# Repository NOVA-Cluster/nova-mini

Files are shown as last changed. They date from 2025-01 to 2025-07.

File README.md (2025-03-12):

# Nova Mini Project Suite

## Overview
The Nova Mini project suite consists of two main components that work together to create an interactive memory game experience:

1. Nova Mini (Receiver)
2. Nova Mini Remote (Sender)

These devices communicate wirelessly using ESP-NOW protocol to create an engaging, interactive game experience based on the classic Simon memory game.

## Components

### Nova Mini (Receiver)
The main game controller that:
- Handles core game logic and state management
- Controls LED patterns and audio feedback
- Processes player inputs
- Manages game progression through levels and rounds
- Provides hardware-level control and feedback

### Nova Mini Remote (Sender)
The user interface controller that:
- Initiates game commands and controls
- Sends instructions to the Nova Mini receiver
- Provides real-time game state updates
- Offers enhanced game mode features
- Enables remote gameplay control

## Technical Stack

### Hardware
Both devices are built on the ESP32 platform, featuring:
- ESP32 microcontroller
- LED indicators for visual feedback
- Push buttons for user input
- Buzzer for audio feedback
- Custom PCB design

### Software
Built using modern embedded development tools and frameworks:
- PlatformIO development environment
- Arduino framework for ESP32
- ESP-NOW protocol for wireless communication
- Custom libraries:
  - ESPUI for web interface
  - AsyncWebServer for configuration
  - MIDI Library for audio control
  - ArduinoJson for data serialization
  - OneButton for enhanced button control

## Communication

The devices use ESP-NOW, a connectionless wireless communication protocol that enables:
- Low-latency communication
- Peer-to-peer data exchange
- Efficient power usage
- Reliable message delivery

## Game Features

- Multiple difficulty levels and progressive rounds
- Real-time LED and audio feedback
- Enhanced state management with stages:
  - Sequence Generation
  - Input Collection
  - Verification
  - Round Transition
  - Game Win/Loss states
- Remote control capabilities
- Cheat mode for testing

## Setup and Configuration

The system includes a web-based configuration interface that allows:
- ESP-NOW pairing between devices
- MAC address management
- Game mode settings
- System preferences

## Development

This project is built using PlatformIO, offering:
- Cross-platform development
- Integrated dependency management
- Automated builds
- Extensive debugging capabilities
- Serial monitoring at 921600 baud

## Project Structure
```
nova-mini/
├── nova-mini (receiver)/        # Main game controller
│   ├── src/                    # Source files
│   ├── hardware/              # PCB and schematic files
│   └── platformio.ini         # Project configuration
└── nova-mini-remote (sender)/  # Remote controller
    ├── src/                    # Source files
    ├── docs/                   # Documentation
    ├── hardware/              # PCB and schematic files
    └── platformio.ini         # Project configuration
```

## Getting Started

1. Clone the repository
2. Open the project in PlatformIO
3. Install required dependencies
4. Configure the ESP-NOW settings through the web interface
5. Upload to respective devices
6. Access the web interface for additional configuration

## Building

Both projects use PlatformIO for building and deployment. Key build flags include:
- Thread name support
- ESP32 exception decoding
- Web server integration
- MIDI capabilities
- Custom debugging options

## Documentation

Detailed documentation is available in the `docs/` directory, including:
- ESP-NOW configuration guide
- Relationship between devices
- Hardware schematics
- PCB design files

## License

[Insert License Information]

## Contributing

[Insert Contribution Guidelines]

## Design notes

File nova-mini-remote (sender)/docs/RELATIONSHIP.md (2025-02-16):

# Relationship between Nova Mini and Nova Mini Remote

## Overview
This document describes how Nova Mini and Nova Mini Remote interact, focusing on the updated game mode and control flow.

## Device Roles

### Nova Mini (Receiver)
- Serves as the hardware controller.
- Monitors game inputs and executes game logic.
- Provides LED and buzzer feedback based on game state changes.

### Nova Mini Remote (Sender)
- Offers a user interface to initiate and control the game.
- Sends local game commands to Nova Mini.
- Updates the game state through real-time interactions.

## Game Mode Enhancements
- The Nova Mini Remote now features an enhanced game mode with improved state management.
- The legacy resetGame() function has been removed.
- A dedicated reset stage (SIMONA_STAGE_RESET) replaces former reset logic and is activated via remote button presses.
- SimonaMessage is used to communicate game stages, levels, and user inputs in real time, ensuring clear feedback and responsive control.

## Workflow
1. Nova Mini Remote issues a game command (e.g., start a new round or reset the game).
2. Nova Mini receives the command, processes it, and updates its game state.
3. SimonaMessage coordinates feedback by triggering appropriate LED, buzzer, and button responses.
4. Together, these interactions create an engaging, interactive game experience.

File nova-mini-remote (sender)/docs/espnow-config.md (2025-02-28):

# ESP-NOW Configuration Tab Documentation

## Overview
The ESP-NOW configuration tab provides a user interface for setting up the wireless communication between the NOVA Mini Remote (sender) and the NOVA Mini (receiver) using ESP-NOW protocol.

## UI Layout
The tab is organized in the following order:
1. Instructions section
2. Local MAC Address display
3. Saved Receiver MAC Address display
4. Status message
5. Set Receiver MAC Address input field

## Interface Elements

### Instructions Section
- Clear step-by-step guidance
- Example MAC address format: 40:91:51:XX:XX:XX
- Example valid addresses for reference
- Format requirements clearly stated

### Local MAC Address
- Displays this device's MAC address
- Read-only label
- Used for reference/debugging

### Saved Receiver MAC Address
- Shows currently configured receiver MAC
- Updates immediately when new MAC is saved
- Shows "Not set" when no MAC is configured

### Status Messages
- Real-time validation feedback
- Shows character count while typing
- Indicates when format is valid
- Prompts to press Enter to save
- Confirms successful saves
- Shows detailed error messages

### MAC Address Input
- Label: "Set Receiver MAC Address"
- Validates in real-time
- Auto-converts to uppercase
- Checks format: XX:XX:XX:XX:XX:XX

## Validation Rules
1. Length must be exactly 17 characters
2. Format must be XX:XX:XX:XX:XX:XX where:
   - X = hex digit (0-9, A-F)
   - : = colon separator
3. Colons must be at positions 3, 6, 9, 12, and 15

## User Workflow
1. View instructions and example format
2. Enter MAC address in input field
3. Receive immediate validation feedback
4. Press Enter when format is valid
5. View confirmation in status and saved MAC display
6. Clear input field ready for next use

## Data Storage
- Stored in preferences namespace "nova"
- Key: "receiver_mac"
- Persists across reboots
- Automatically loaded on startup

## ESP-NOW Integration
- MAC address saved in preferences
- Used to initialize ESP-NOW peer
- Automatically reconnects after changes

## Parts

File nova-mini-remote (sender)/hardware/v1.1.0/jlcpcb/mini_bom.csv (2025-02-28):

Comment | Designator | Footprint | LCSC Part #
 | JP_ENABLE | 1X02
 | JP3 | 2X02
 | ULN2 | SO18L | C9683
1k | R1 R125 R126 R127 R128 R129 R130 R139 | R0603 | C21190
1uf | C4 | C0805 | C15849
2.2k | R131 | R0603 | C4190
10k | R2 R133 R134 R135 R136 R137 | R0603 | C25804
10uf | C1 C2 C3 C5 | C0603 | C19702
500ma Fuse | F2 | FUSC4632X160 | C70113
1500ma Fuse | F1 | FUSC4632X160 | C78695
110990030 | J1 | SEEED_110990030
B4B-PH-K | BUTTON_BLUE BUTTON_ENABLE BUTTON_GREEN BUTTON_RED BUTTON_WHITE BUTTON_YELLOW | B4B-PH-K
CON_POWER | POWER_IN | MKDSN1 5/4-5 08
ESP32DEVKITV1 | U$1 | ESP32-DEVKITV1
LD117AS12TR | IC2 | SOT223 | C6187
MAX488CSA | IC1 | SO08 | C179693
MOMENTARY-SWITCH-SPST-PTH-6.0MM | S1 S2 S3 S4 S5 | TACTILE_SWITCH_PTH_6.0MM
RJ45 | J2 | RJ45-8
R_1K_0603 | R132 | R0603 | C21190
R_56R_0603 | R221 R222 | R0603 | C25196
R_82R_0603 | R224 | R0603 | C23255
R_270R_0603 | R220 R223 | R0603 | C22966
blue | D83 D88 D93 | LED-0603 | C72041
green | D82 D87 D92 | LED-0603 | C72043
red | D81 D86 D91 | LED-0603 | C2286
white | D1 D84 D89 | LED-0603 | C2290
yellow | D85 D90 D94 | LED-0603 | C72038

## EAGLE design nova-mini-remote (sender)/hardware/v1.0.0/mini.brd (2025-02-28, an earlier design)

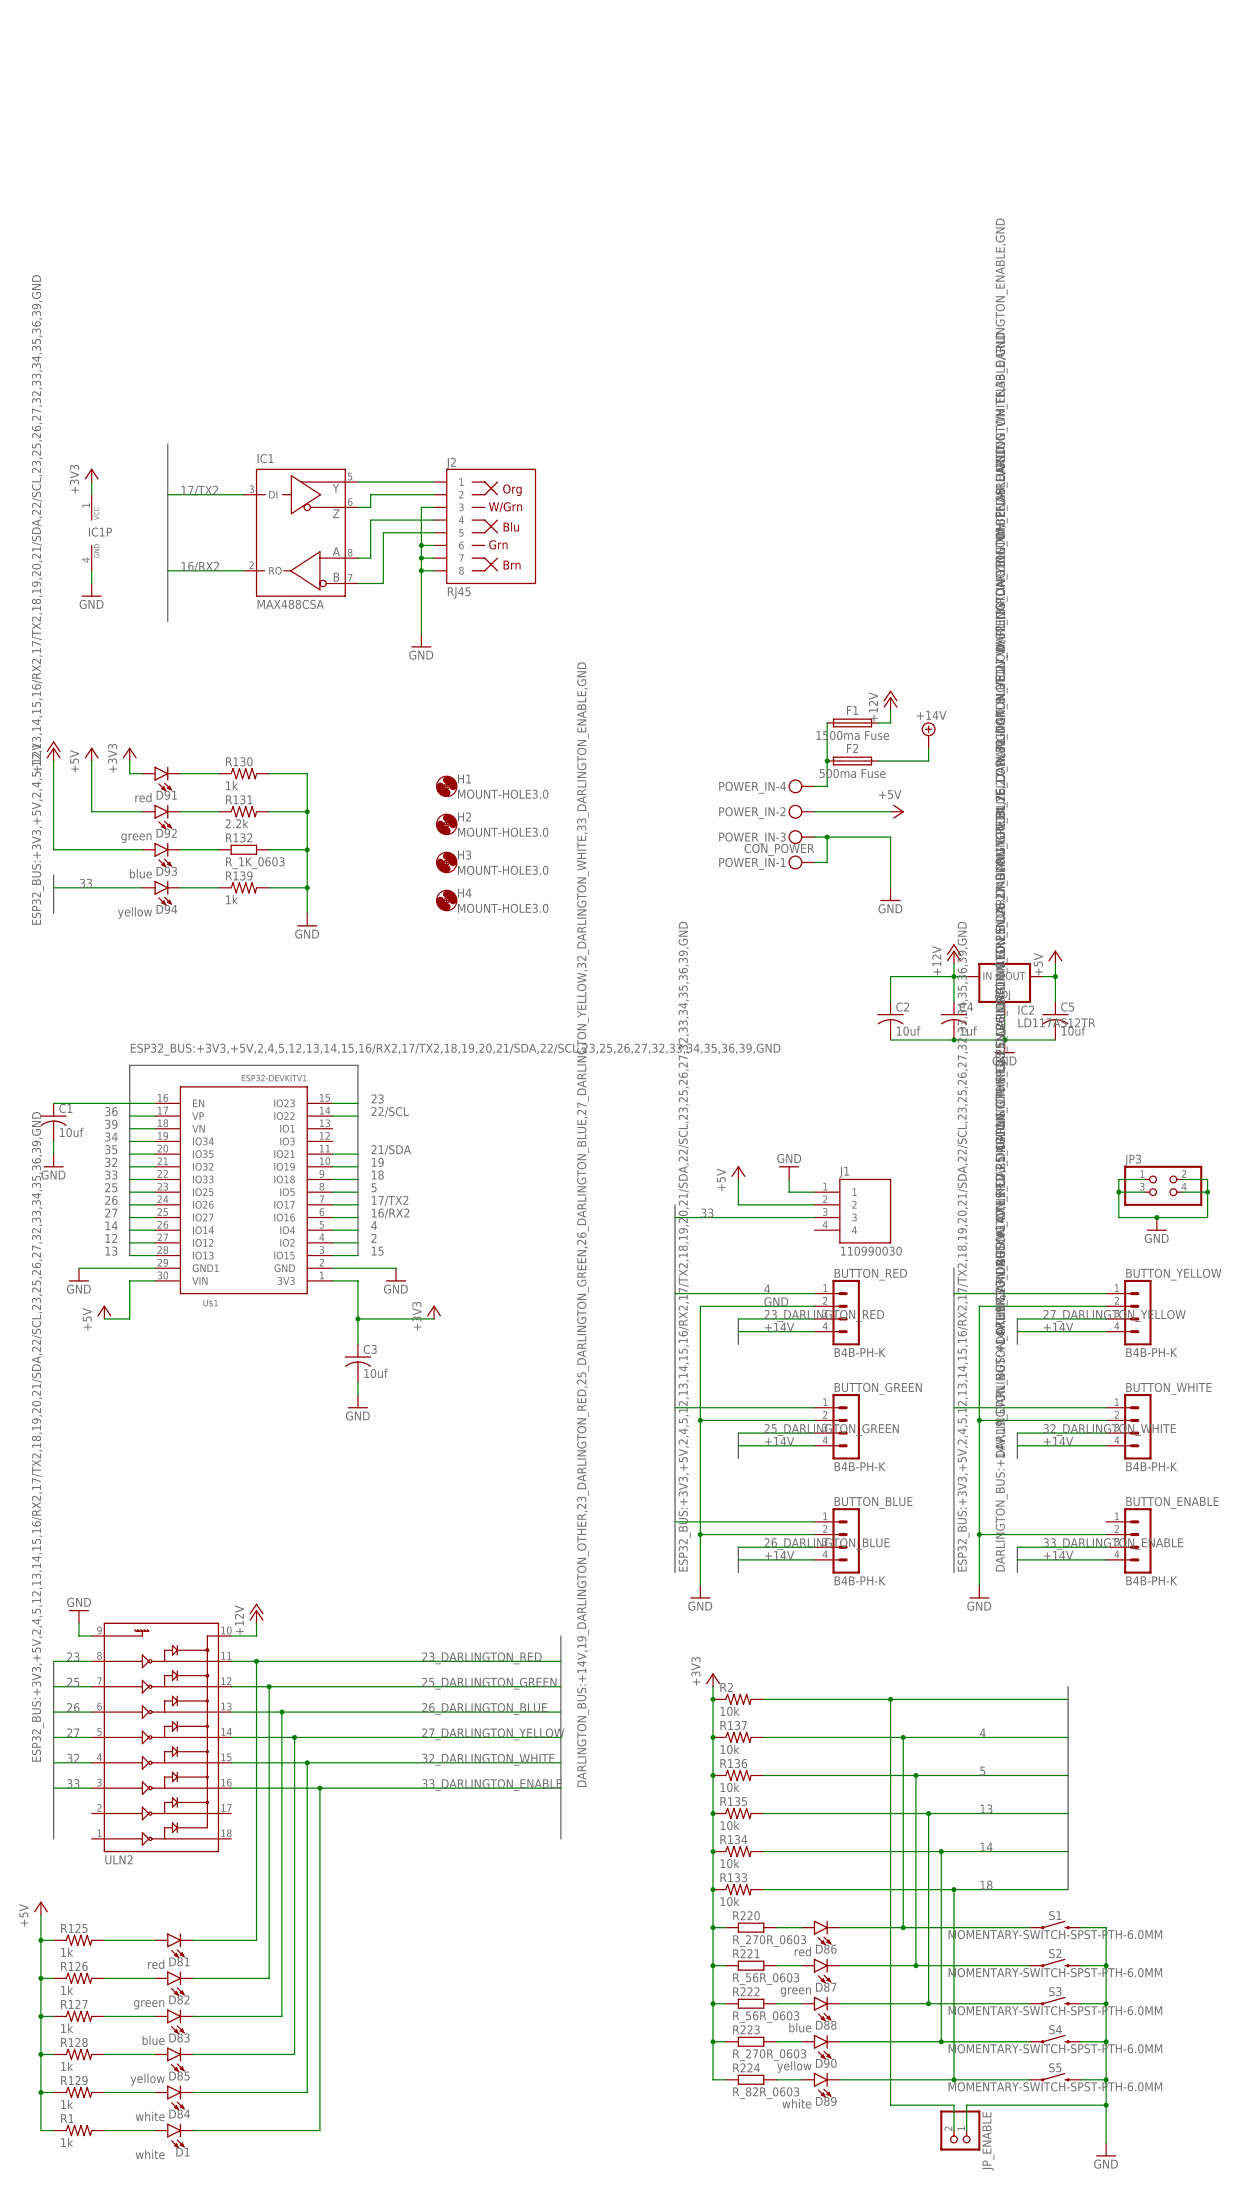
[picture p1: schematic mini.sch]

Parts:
BUTTON_BLUE: B4B-PH-K
BUTTON_ENABLE: B4B-PH-K
BUTTON_GREEN: B4B-PH-K
BUTTON_RED: B4B-PH-K
BUTTON_WHITE: B4B-PH-K
BUTTON_YELLOW: B4B-PH-K
C1, C2, C3, C5: 10uf; C0603; LCSC_PART C19702
C4: 1uf; C0805; LCSC_PART C15849
D1, D84, D89: white; LED-0603; LCSC_PART C2290
D81, D86, D91: red; LED-0603; LCSC_PART C2286
D82, D87, D92: green; LED-0603; LCSC_PART C72043
D83, D88, D93: blue; LED-0603; LCSC_PART C72041
D85, D90, D94: yellow; LED-0603; LCSC_PART C72038
F1: 1500ma Fuse; FUSC4632X160; LCSC_PART C78695
F2: 500ma Fuse; FUSC4632X160; LCSC_PART C70113
H1, H2, H3, H4: MOUNT-HOLE3.0; 3,0
IC1: MAX488CSA; SO08; LCSC_PART C179693
IC2: LD117AS12TR; SOT223; LCSC_PART C6187
J1: 110990030; SEEED_110990030
J2: RJ45; RJ45-8
JP3: PINHD-2X2; 2X02
JP_ENABLE: PINHD-1X2; 1X02
POWER_IN: CON_POWER; MKDSN1,5/4-5,08
R1, R125, R126, R127, R128, R129, R130, R139: 1k; R0603; LCSC_PART C21190
R2, R133, R134, R135, R136, R137: 10k; R0603; LCSC_PART C25804
R131: 2.2k; R0603; LCSC_PART C4190
R132: R_1K_0603; R0603
R220, R223: R_270R_0603; R0603
R221, R222: R_56R_0603; R0603
R224: R_82R_0603; R0603
S1, S2, S3, S4, S5: MOMENTARY-SWITCH-SPST-PTH-6.0MM; TACTILE_SWITCH_PTH_6.0MM
U$1: ESP32DEVKITV1; ESP32-DEVKITV1
ULN2: ULN2803SOICW; SO18L

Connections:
2: U$1.4 (IO2)
4: BUTTON_RED.1, D86.C, R137.2, S1.1, U$1.5 (IO4)
5: BUTTON_GREEN.1, D87.C, R136.2, S2.1, U$1.8 (IO5)
12: U$1.27 (IO12)
13: BUTTON_BLUE.1, D88.C, R135.2, S3.1, U$1.28 (IO13)
14: BUTTON_YELLOW.1, D90.C, R134.2, S4.1, U$1.26 (IO14)
15: U$1.3 (IO15)
16/RX2: IC1.2 (RO), U$1.6 (IO16)
17/TX2: IC1.3 (DI), U$1.7 (IO17)
18: BUTTON_WHITE.1, D89.C, R133.2, S5.1, U$1.9 (IO18)
19: JP_ENABLE.2, R2.2, U$1.10 (IO19)
21/SDA: U$1.11 (IO21)
22/SCL: U$1.14 (IO22)
23: U$1.15 (IO23), ULN2.8
23_DARLINGTON_RED: BUTTON_RED.3, D81.C, ULN2.11
25: U$1.23 (IO25), ULN2.7
25_DARLINGTON_GREEN: BUTTON_GREEN.3, D82.C, ULN2.12
26: U$1.24 (IO26), ULN2.6
26_DARLINGTON_BLUE: BUTTON_BLUE.3, D83.C, ULN2.13
27: U$1.25 (IO27), ULN2.5
27_DARLINGTON_YELLOW: BUTTON_YELLOW.3, D85.C, ULN2.14
32: U$1.21 (IO32), ULN2.4
32_DARLINGTON_WHITE: BUTTON_WHITE.3, D84.C, ULN2.15
33: D94.A, J1.3, U$1.22 (IO33), ULN2.3
33_DARLINGTON_ENABLE: BUTTON_ENABLE.3, D1.C, ULN2.16
34: U$1.19 (IO34)
35: U$1.20 (IO35)
36: U$1.17 (VP)
39: U$1.18 (VN)
+3V3: C3.1, D91.A, IC1.1 (VCC), R2.1, R133.1, R134.1, R135.1, R136.1, R137.1, R220.1, R221.1, R222.1, R223.1, R224.1, U$1.1 (3V3)
+5V: C5.1, D92.A, IC2.4 (OUT), J1.2, POWER_IN.2, R1.1, R125.1, R126.1, R127.1, R128.1, R129.1, U$1.30 (VIN)
+12V: C2.1, C4.1, D93.A, F1.2, IC2.3 (IN), ULN2.10
+14V: BUTTON_BLUE.4, BUTTON_ENABLE.4, BUTTON_GREEN.4, BUTTON_RED.4, BUTTON_WHITE.4, BUTTON_YELLOW.4, F2.2
GND: BUTTON_BLUE.2, BUTTON_ENABLE.2, BUTTON_GREEN.2, BUTTON_RED.2, BUTTON_WHITE.2, BUTTON_YELLOW.2, C1.2, C2.2, C3.2, C4.2, C5.2, IC1.4 (GND), IC2.1 (ADJ), J1.1, J2.3, J2.6, J2.7, J2.8, JP3.1, JP3.2, JP3.3, JP3.4, JP_ENABLE.1, POWER_IN.1, POWER_IN.3, R130.2, R131.2, R132.2, R139.2, S1.3 (2), S2.3 (2), S3.3 (2), S4.3 (2), S5.3 (2), U$1.2 (GND), U$1.29 (GND1), ULN2.9
unnamed: C1.1, U$1.16 (EN)
unnamed: D1.A, R1.2
unnamed: IC1.5 (Y), J2.1
unnamed: IC1.6 (Z), J2.2
unnamed: IC1.8 (A), J2.4
unnamed: IC1.7 (B), J2.5
unnamed: D84.A, R129.2
unnamed: D85.A, R128.2
unnamed: D83.A, R127.2
unnamed: D82.A, R126.2
unnamed: D81.A, R125.2
unnamed: D91.C, R130.1
unnamed: D92.C, R131.1
unnamed: D93.C, R132.1
unnamed: D94.C, R139.1
unnamed: D86.A, R220.2
unnamed: D87.A, R221.2
unnamed: D88.A, R222.2
unnamed: D90.A, R223.2
unnamed: D89.A, R224.2
unnamed: F1.1, F2.1, POWER_IN.4

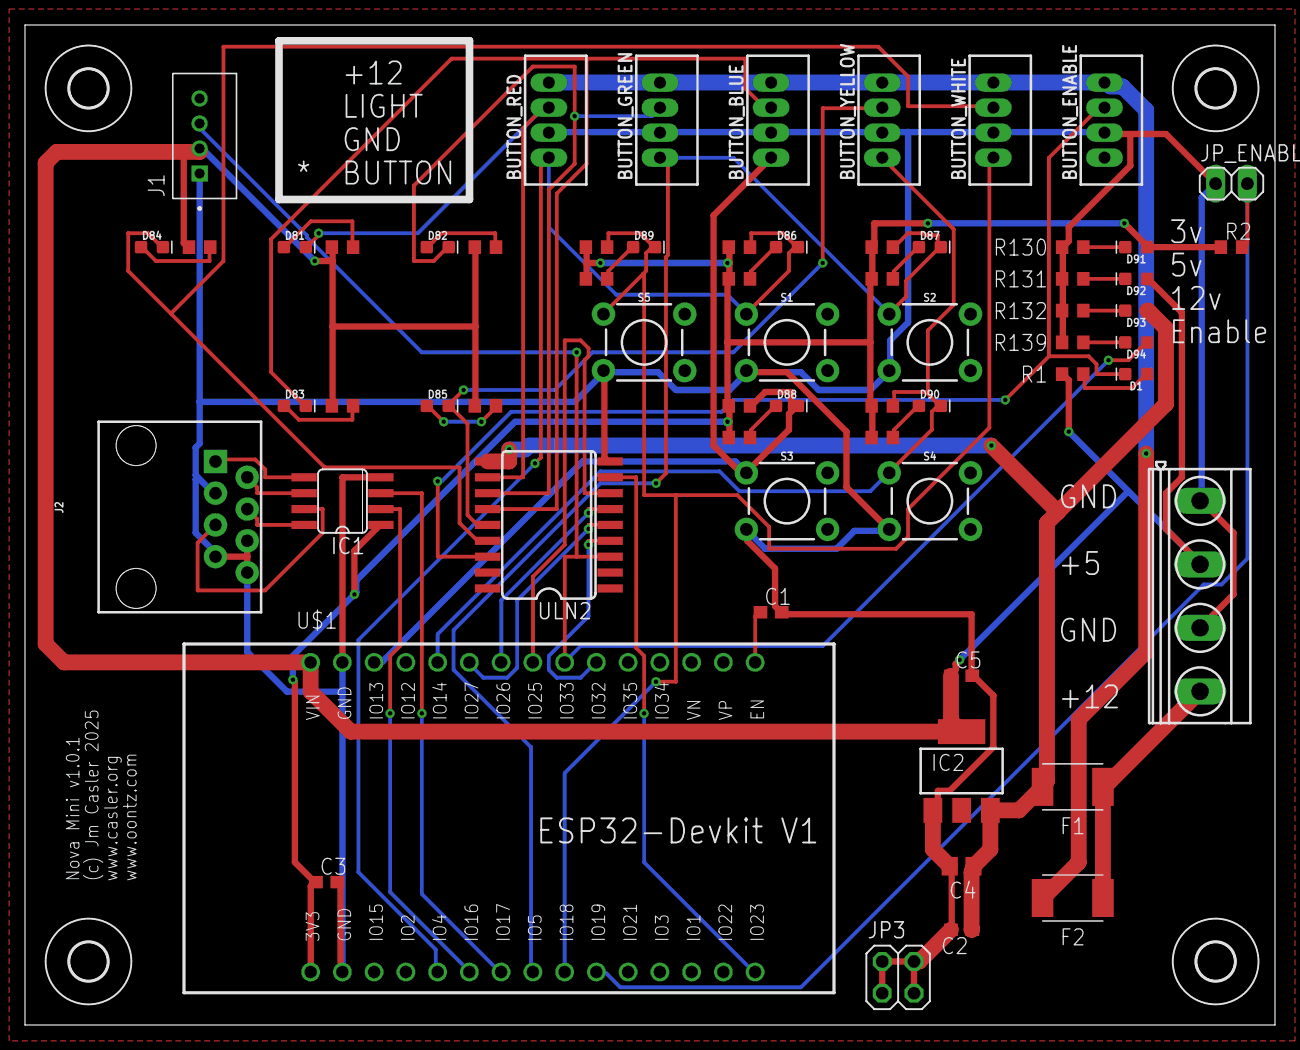
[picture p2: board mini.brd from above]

Board: 2 copper layers, 100.0 x 80.0 mm, 67 parts (0 on the bottom side), 46 nets.

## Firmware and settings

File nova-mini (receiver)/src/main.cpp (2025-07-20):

#include <ShiftRegister74HC595.h>
#include "configuration.h" // Renamed include from pin_config.h
#include <iostream>
#include <memory>
#include <Arduino.h>

#include <DNSServer.h>
#include <WiFi.h>
#include <LittleFS.h>
#include <AsyncTCP.h>
#include "ESPAsyncWebServer.h"
#include <ESPUI.h>
#include "configuration.h"
#include "main.h"                   // Added include for initEspNowReceiver and relay control prototypes
#include "utilities/Utilities.h"    // Updated path
#include <FastLED.h>                // Added support for SM16703 using FastLED
#include "SimonaDisplaySequences.h" // New include for LED animation sequences

#include "Web.h"
#include <stdarg.h>
#include "freertos/semphr.h" // Corrected include directive

#include "Tasks.h" // New include for task declarations

// Define the number of 74HC595 chips in cascade
// Removed: const uint8_t NUMBER_OF_SHIFT_REGISTERS = 1;

// Create a ShiftRegister74HC595 object using value from configuration.
ShiftRegister74HC595<NUMBER_OF_SHIFT_REGISTERS> sr(HT74HC595_DATA, HT74HC595_CLOCK, HT74HC595_LATCH); // (dataPin, clockPin, latchPin)

void TaskWeb(void *pvParameters);
void TaskOutputs(void *pvParameters);
void TaskPulseRelay(void *pvParameters);
void TaskFastLED(void *pvParameters); // New task for SM16703 LED control using FastLED

DNSServer dnsServer;

// Configurable maximum relay duration in ms
// Removed: const uint32_t MAX_RELAY_DURATION = 250;

// Updated non-blocking relay control implementation

bool poofersEnabled = true; // Global flag; true by default

// Function to trigger a relay for a specified duration (in ms), clamped by MAX_RELAY_DURATION.
void triggerRelay(int channel, int duration)
{
    // If the relay is in channels 0-5 (i.e. for poofers) and they are disabled, do nothing.
    if (channel < 6 && !poofersEnabled)
        return;
    if (channel < 0 || channel >= NUM_RELAYS)
        return;
    sr.set(channel, HIGH);
    relayTasks[channel].active = true;
    relayTasks[channel].longActive = false;
    relayTasks[channel].startTime = millis();
    // Use the requested duration but TaskOutputs will enforce MAX_RELAY_DURATION.
    relayTasks[channel].offTime = millis() + duration;
}

// New function to trigger a relay disregarding the MAX_RELAY_DURATION clamp.
void triggerRelayLong(int channel, int duration)
{
    if (channel < 6 && !poofersEnabled)
        return;
    if (channel < 0 || channel >= NUM_RELAYS)
        return;
    sr.set(channel, HIGH);
    relayTasks[channel].active = true;
    relayTasks[channel].longActive = true;
    relayTasks[channel].startTime = millis();
    relayTasks[channel].offTime = millis() + duration;
}

// New function to disable a relay.
void disableRelay(int channel)
{
    if (channel < 0 || channel >= NUM_RELAYS)
        return;
    sr.set(channel, LOW);
    relayTasks[channel].active = false;
}

#define NUM_LEDS_FOR_TEST 4   // Number of LEDs for testing
CRGB leds[NUM_LEDS_FOR_TEST]; // LED array for SM16703

// Global variable definitions
int currentLitButton = 0;
int currentLastPressedButton = 0; // added definition for msg.lastPressedButton used in animations
uint32_t currentLastPressedMessageId = 0; // track last message_id for INPUT_COLLECTION animations

// Add WiFi event handler function
void WiFiEvent(WiFiEvent_t event)
{
    Serial.printf("[WiFi-event] event: %d\n", event);

    switch (event)
    {
    case SYSTEM_EVENT_WIFI_READY:
        Serial.println("WiFi interface ready");
        break;
    case SYSTEM_EVENT_SCAN_DONE:
        Serial.println("Completed scan for access points");
        break;
    case SYSTEM_EVENT_STA_START:
        Serial.println("WiFi client started");
        break;
    case SYSTEM_EVENT_AP_START:
        Serial.println("WiFi AP started");
        Serial.print("AP IP address: ");
        Serial.println(WiFi.softAPIP());
        Serial.print("AP MAC address: ");
        Serial.println(WiFi.softAPmacAddress());
        break;
    case SYSTEM_EVENT_AP_STOP:
        Serial.println("WiFi AP stopped");
        break;
    case SYSTEM_EVENT_AP_STACONNECTED:
        Serial.println("Client connected");
        break;
    case SYSTEM_EVENT_AP_STADISCONNECTED:
        Serial.println("Client disconnected");
        break;
    }
}

void setup()
{

    // Use configuration values for reset.
    pinMode(RESET_PIN, OUTPUT);
    digitalWrite(RESET_PIN, LOW);  // Set LOW to trigger reset
    delay(RESET_LOW_DELAY_MS);     // Wait for reset to take effect
    digitalWrite(RESET_PIN, HIGH); // Set HIGH to end reset

    delay(SERIAL_MONITOR_DELAY_MS); // Wait for the serial monitor to open

// Enable core dumps for better debugging
#ifdef DEBUG
    ESP_LOGI(TAG, "Enabling core dumps");
    esp_core_dump_init();
#endif

    Serial.begin(921600); // Updated baud rate to match monitor_speed
    initSafeSerial();     // Initialize safe serial printing (new)

    NovaLogo();

    safeSerialPrintf("NOVA: MINI\n");
    safeSerialPrintf("setup() is running on core %d\n", xPortGetCoreID());

    Serial.setDebugOutput(true);

    safeSerialPrintf("Power on and set the 74HC595 to output disable mode\n");
    pinMode(HT74HC595_OUT_EN, OUTPUT);
    digitalWrite(HT74HC595_OUT_EN, HIGH); // Turn off output data HT74HC595

    safeSerialPrintf("Set all relay outputs to low level\n");
    // HT74HC595->setAllLow();
    sr.setAllLow();

    safeSerialPrintf("Set GPIO4 to low level to enable relay output\n");
    digitalWrite(HT74HC595_OUT_EN, LOW);

    // Initialize LittleFS and try to recover if mount fails.
    if (!LittleFS.begin())
    {
        safeSerialPrintf("LittleFS mount failed, formatting...\n");
        LittleFS.format();
        if (!LittleFS.begin())
        {
            safeSerialPrintf("LittleFS mount failed after format!\n");
        }
        else
        {
            safeSerialPrintf("LittleFS mount succeeded after format.\n");
        }
    }
    else
    {
        safeSerialPrintf("LittleFS mounted successfully.\n");
    }

    String macAddress = WiFi.macAddress();
    String AP_String = "NovaMini_" + getLastFourOfMac(); // Replace existing MAC parsing code with this line

    Serial.printf("Setting WiFi mode to WIFI_AP_STA... ");

    // Consolidated WiFi setup with proper sequencing
    Serial.println("\n=== WiFi Setup Start ===");
    WiFi.onEvent(WiFiEvent);

    Serial.printf("Setting WiFi mode to WIFI_AP_STA... ");
    if (WiFi.mode(WIFI_AP_STA))
    {
        Serial.println("SUCCESS");
    }
    else
    {
        Serial.println("FAILED");
        ESP.restart(); // Restart if WiFi mode setting fails
    }

    delay(100); // Small delay after mode change

    Serial.printf("Starting AP with SSID: %s... ", AP_String.c_str());
    if (WiFi.softAP(AP_String.c_str(), "scubadandy"))
    {
        Serial.println("SUCCESS");
    }
    else
    {
        Serial.println("FAILED");
        ESP.restart(); // Restart if AP setup fails
    }

    WiFi.setSleep(false); // Disable power saving
    delay(100);           // Give AP time to start up

    Serial.println("AP Status:");
    Serial.printf("- SSID: %s\n", WiFi.softAPSSID().c_str());
    Serial.printf("- IP: %s\n", WiFi.softAPIP().toString().c_str());
    Serial.printf("- MAC: %s\n", WiFi.softAPmacAddress().c_str());
    Serial.printf("- Channel: %d\n", WiFi.channel());

    if (dnsServer.start(53, "*", WiFi.softAPIP()))
    {
        Serial.println("DNS Server started successfully");
    }
    else
    {
        Serial.println("DNS Server failed to start");
    }

    Serial.println("=== WiFi Setup Complete ===\n");

    // Continue with rest of setup
    safeSerialPrintf("Setting up Webserver\n");
    webSetup();
    safeSerialPrintf("Setting up Webserver - Done\n");

    safeSerialPrintf("Create TaskWeb\n");
    delay(10);
    xTaskCreate(&TaskWeb, "TaskWeb", 8 * 1024, NULL, 5, NULL);
    delay(10);
    safeSerialPrintf("Create TaskWeb - Done\n");
    delay(10);

    safeSerialPrintf("Create TaskOutputs\n");
    delay(10);
    xTaskCreate(&TaskOutputs, "TaskOutputs", 8 * 1024, NULL, 5, NULL); // Now starting TaskOutputs
    delay(10);
    safeSerialPrintf("Create TaskOutputs - Done\n");

    // Create new TaskPulseRelay to handle relay #8 pulsing.
    safeSerialPrintf("Create TaskPulseRelay\n");
    delay(10);
    xTaskCreate(&TaskPulseRelay, "TaskPulseRelay", 6 * 1024, NULL, 5, NULL);
    delay(10);
    safeSerialPrintf("Create TaskPulseRelay - Done\n");

    // Call initEspNowReceiver to initialize receiver functionality.
    initEspNowReceiver();

    // Initialize FastLED for SM16703 LED support
    FastLED.addLeds<SM16703, LED_PIN_FASTLED, RGB>(leds, NUM_LEDS_FOR_TEST);

    // Create new TaskFastLED for SM16703 control
    safeSerialPrintf("Create TaskFastLED\n");
    xTaskCreate(&TaskFastLED, "TaskFastLED", 8 * 1024, NULL, 5, NULL);

    // New: Print device information
    Serial.println("Device Information:");
    Serial.print("MAC Address: ");
    Serial.println(WiFi.macAddress());
    Serial.print("IP Address: ");
    Serial.println(WiFi.localIP());
    Serial.print("AP IP Address: ");
    Serial.println(WiFi.softAPIP());
    Serial.print("Free Heap: ");
    Serial.println(ESP.getFreeHeap());
    // Added new stats
    Serial.print("CPU Frequency (MHz): ");
    Serial.println(ESP.getCpuFreqMHz());
    Serial.print("SDK Version: ");
    Serial.println(ESP.getSdkVersion());
}

// Removed unused controlRelay function

void loop()
{
    // Do nothing in here. Everything must be in Tasks.
}

// Removed task definitions (TaskWeb, TaskOutputs, TaskPulseRelay, TaskFastLED)
// They have been moved to Tasks.cpp

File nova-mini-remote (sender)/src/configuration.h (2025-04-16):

#ifndef CONFIGURATION_H
#define CONFIGURATION_H

// Pin Definitions for LEDs and Buttons
#define LED_RED 23
#define LED_GREEN 25
#define LED_BLUE 26
#define LED_YELLOW 27
#define LED_RESET 32

#define BTN_RED 4
#define BTN_GREEN 5
#define BTN_BLUE 13
#define BTN_YELLOW 14
#define BTN_RESET 18

// LEDC (PWM) Configuration
#define LEDC_FREQ_HZ      5000
#define LEDC_RESOLUTION   8       // 8-bit resolution (0-255)
#define LEDC_FULL_DUTY    255     // Full brightness duty cycle
#define LEDC_DIM_DUTY     3      // 10% brightness duty cycle (255 * 0.10)

#define LEDC_CHANNEL_RED      0
#define LEDC_CHANNEL_GREEN    1
#define LEDC_CHANNEL_BLUE     2
#define LEDC_CHANNEL_YELLOW   3
#define LEDC_CHANNEL_RESET    4

// Game configuration constants
#define SIMONA_INPUT_TIMEOUT_SECONDS 30
#define SIMONA_DEBUG_TIMEOUT 0  // Set to 1 to enable timeout debug messages
#define LEVELS_PER_ROUND_DEFAULT 1

// ESP-NOW configuration
#define MAX_RETRIES 5       // Maximum number of retries for sending ESP-NOW messages
#define ACK_TIMEOUT_MS 12  // Timeout in milliseconds to wait for an acknowledgement

// Task reporting interval (matching receiver implementation)
#define REPORT_TASK_INTERVAL (120 * 1000) // How often to report task status in milliseconds

// Preferences configuration
#define PREF_NAMESPACE "nova"
#define PREF_KEY_CHEAT_MODE "cheat_mode"
#define PREF_KEY_REMOTE_MAC "remote_mac"
#define PREF_KEY_RECEIVER_MAC "receiver_mac"
#define PREF_KEY_WIRELESS_ENABLED "wireless_en"
#define PREF_KEY_GAME_ENABLED "game_en"
#define PREF_KEY_SEQUENCE_LOCAL_ECHO "seq_echo"

// RMT MIDI Output Configuration
#define RMT_BIT_DURATION_TICKS 32  // Nova mini-specific MIDI timing

// E-Stop Configuration
#define ESTOP_PIN 19
#define ESTOP_TASK_INTERVAL 2  // Check E-Stop status every 2ms
#define ESTOP_DEBOUNCE_MS 50     // Debounce time in milliseconds

#endif // CONFIGURATION_H

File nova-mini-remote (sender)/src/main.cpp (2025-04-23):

#include <Arduino.h>
#include "configuration.h"
#include "Simona.h"
#include "utilities/utilities.h"
#include "freertos/FreeRTOS.h"
#include "freertos/task.h"
#include "midi/MIDIControl.hpp"
#include <MIDI.h>
#include "EspNow.h"
#include <WiFi.h>
#include <WiFiType.h>
#include "Web.h"
#include "Tasks.h"
#include "EStop.h"
#include "wifi_config.h"

uint8_t buttons[4] = {BTN_RED, BTN_GREEN, BTN_BLUE, BTN_YELLOW};
uint8_t leds[4] = {LED_RED, LED_GREEN, LED_BLUE, LED_YELLOW};
const char *buttonColors[4] = {"RED", "GREEN", "BLUE", "YELLOW"};
const char *ledColors[4] = {"RED", "GREEN", "BLUE", "YELLOW"};

boolean button[4] = {0, 0, 0, 0};

void WiFiEventHandler(WiFiEvent_t event)
{
  switch (event)
  {
  case SYSTEM_EVENT_STA_START:
    Serial.println("Station Mode Started");
    break;
  case SYSTEM_EVENT_AP_START:
    Serial.println("AP Mode Started");
    break;
  case SYSTEM_EVENT_STA_CONNECTED:
    Serial.println("Connected to AP");
    break;
  case SYSTEM_EVENT_AP_STACONNECTED:
    Serial.println("Station connected to ESP32 AP");
    break;
  case SYSTEM_EVENT_STA_DISCONNECTED:
    Serial.println("Disconnected from AP");
    break;
  case SYSTEM_EVENT_AP_STADISCONNECTED:
    Serial.println("Station disconnected from ESP32 AP");
    break;
  }
}

void checkWiFiStatus(void *parameter)
{
  while (true)
  {
    Serial.printf("AP Stations connected: %d\n", WiFi.softAPgetStationNum());
    Serial.printf("WiFi Status: %s\n", WiFi.status() == WL_CONNECTED ? "Connected" : "Disconnected");
    vTaskDelay(pdMS_TO_TICKS(30000)); // Check every 30 seconds
  }
}

// Function to initialize LED with PWM
void initLedPWM(uint8_t pin, uint8_t channel) {
  ledcSetup(channel, LEDC_FREQ_HZ, LEDC_RESOLUTION);
  ledcAttachPin(pin, channel);
}

void setup()
{
  Serial.begin(921600); // Initialize serial communication for debugging
  delay(2000);          // Add delay to allow the serial monitor to connect

  // Initialize safe serial printing
  initSafeSerial();

  safeSerialPrintf("Initializing Nova Mini Remote\n");

  randomSeed(esp_random()); // Seed the random number generator with more entropy

  initializeMIDI();

  NovaLogo(); // Print the Nova logo

  // Initialize button pins
  pinMode(BTN_RED, INPUT);
  pinMode(BTN_GREEN, INPUT);
  pinMode(BTN_BLUE, INPUT);
  pinMode(BTN_YELLOW, INPUT);
  pinMode(BTN_RESET, INPUT);

  // Initialize LEDs with PWM
  initLedPWM(LED_RED, LEDC_CHANNEL_RED);
  initLedPWM(LED_GREEN, LEDC_CHANNEL_GREEN);
  initLedPWM(LED_BLUE, LEDC_CHANNEL_BLUE);
  initLedPWM(LED_YELLOW, LEDC_CHANNEL_YELLOW);
  initLedPWM(LED_RESET, LEDC_CHANNEL_RESET);

  // Initialize E-Stop pin
  pinMode(ESTOP_PIN, INPUT_PULLUP);

  if (0)
  {
    Serial.println("   Welcome To   ");
    Serial.println("> Simona <");
    Serial.println();
  }

  // Create FreeRTOS tasks

  WiFi.onEvent(WiFiEventHandler); // Register event handler

  // WiFi Setup
  WiFi.mode(WIFI_AP_STA); // Set WiFi to AP+STA mode
  WiFi.disconnect();
  WiFi.setSleep(false); // Disable power saving

  // Create AP name with MAC suffix
  String apName = "NovaMiniRemote_" + getLastFourOfMac();
  WiFi.softAP(apName.c_str(), "scubadandy");

  // Print network information
  Serial.println("Device Information:");
  Serial.print("MAC Address: ");
  Serial.println(WiFi.macAddress());
  Serial.print("AP Name: ");
  Serial.println(apName);
  Serial.print("AP IP Address: ");
  Serial.println(WiFi.softAPIP());
  Serial.print("STA IP Address: ");
  Serial.println(WiFi.localIP());
  Serial.print("Free Heap: ");
  Serial.println(ESP.getFreeHeap());
  Serial.print("CPU Frequency (MHz): ");
  Serial.println(ESP.getCpuFreqMHz());
  Serial.print("SDK Version: ");
  Serial.println(ESP.getSdkVersion());

  espNowSetup();

  webSetup();

  // Initialize Simona singleton
  Simona::initInstance(buttons, leds, buttonColors, ledColors);

  // Create all FreeRTOS tasks
  createTasks();

  playStartupMusic(); // New: play startup music (short, under 1.5 seconds)
}

void loop()
{
  // Empty loop as tasks are handled by FreeRTOS
}

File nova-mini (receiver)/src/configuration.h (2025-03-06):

/*
 * @Description: None
 * @version: None
 * @Author: None
 * @Date: 2023-06-05 13:01:59
 * @LastEditors: Please set LastEditors
 * @LastEditTime: 2024-07-19 09:15:01
 */
#pragma once

// HT74HC595
#define HT74HC595_CLOCK 5
#define HT74HC595_LATCH 6
#define HT74HC595_DATA 7
#define HT74HC595_OUT_EN 4

// New configuration values moved from main.cpp:
#define NUMBER_OF_SHIFT_REGISTERS 1
#define MAX_RELAY_DURATION 250

// Delay to wait for serial monitor to open (ms)
#define SERIAL_MONITOR_DELAY_MS 3000

// Reset pin configuration
#define RESET_PIN 39
#define RESET_LOW_DELAY_MS 50

#define REPORT_TASK_INTERVAL (120 * 1000) // How often to report task status in milliseconds

#define LED_PIN_FASTLED 8  // Use GPIO8 for FastLED LEDs

// Preferences configuration
#define PREF_NAMESPACE "nova"
#define PREF_KEY_REMOTE_MAC "remote_mac"

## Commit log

2024-12-28 Switch to esp32s3box
2024-12-28 refactor relay control and begin adding threading
    [configuration.h]
2025-02-09 add a few more relay functions
2025-02-15 move pin defines to configuration
    [configuration.h]
2025-02-20 Add support for the output LEDs
    [configuration.h]
2025-02-20 new game lost and game reset animations
    [SimonaDisplaySequences.cpp]
2025-02-21 stage sequence animation (not done)
2025-02-21 add relay control to sequence generation, input and win
2025-02-26 Cleanup web, fix web loop in tasks, fix mac address
    [Utilities.cpp, Web.cpp, main.cpp]
2025-03-01 change wifi status print to once every 30 seconds
2025-03-01 Messages in the last 5 minutes was not accurate, fixed
    [EspNow.cpp, Web.cpp]
2025-03-01 Wireless enable and game enable toggle
2025-03-01 Factory reset and status updates
    [Web.cpp]
2025-03-01 small refactoring of sender config
    [configuration.h]
2025-03-01 fix stage lookup
2025-03-01 minor changes
    [configuration.h]
2025-03-01 Factory reset, poofer enable switch, device stats
    [Web.cpp, main.cpp]
2025-03-01 Refactoring and moving things into folders
    [configuration.h]
2025-03-03 use thread safe delays
2025-03-03 Invert led output states
    [Simona.cpp, main.cpp]
2025-03-03 start with the buttons on and dim when a button is pushed.
    [configuration.h]
2025-03-03 set dim
    [configuration.h]
2025-03-03 Fixed led <-> relay mapping
    [Simona.cpp]
2025-03-03 Fix led / relay mapping
    [SimonaDisplaySequences.cpp]
2025-03-06 Refactored preferencesmanager
    Will use this on Nova as well.
    [configuration.h]
2025-03-09 Bump arduinojson
2025-03-09 Update RMT library to code ticks
    [configuration.h]
2025-03-09 Change name of button constants
2025-03-11 Revert "Change name of button constants"
    This reverts commit e887426c8f1fb3a70d76e88bdc107bca3ef324e2.
    [Simona.cpp, Simona.h, main.cpp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]
2025-03-12 Fix problem with RMT and add readme
    [configuration.h]
2025-04-16 Add estop config
    [configuration.h]
2025-04-23 Remove wifi multi. causes problems with espnow
    [main.cpp]
2025-07-20 Add debug print for input collection stage
    Inserted a Serial.println statement to indicate when SIMONA_STAGE_INPUT_COLLECTION is entered, aiding in debugging and stage tracking.
2025-07-20 Track message_id for input collection animations
    Introduces currentLastPressedMessageId to track the last message_id during INPUT_COLLECTION stage, enabling more precise relay and LED animation timing. Updates SimonaDisplay, SimonaDisplaySequences,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

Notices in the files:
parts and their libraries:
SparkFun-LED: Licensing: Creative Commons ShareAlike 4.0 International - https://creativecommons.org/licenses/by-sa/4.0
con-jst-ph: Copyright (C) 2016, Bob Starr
